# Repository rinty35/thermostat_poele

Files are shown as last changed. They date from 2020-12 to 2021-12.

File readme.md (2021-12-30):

# Thermostat DIY Poêle à pellets
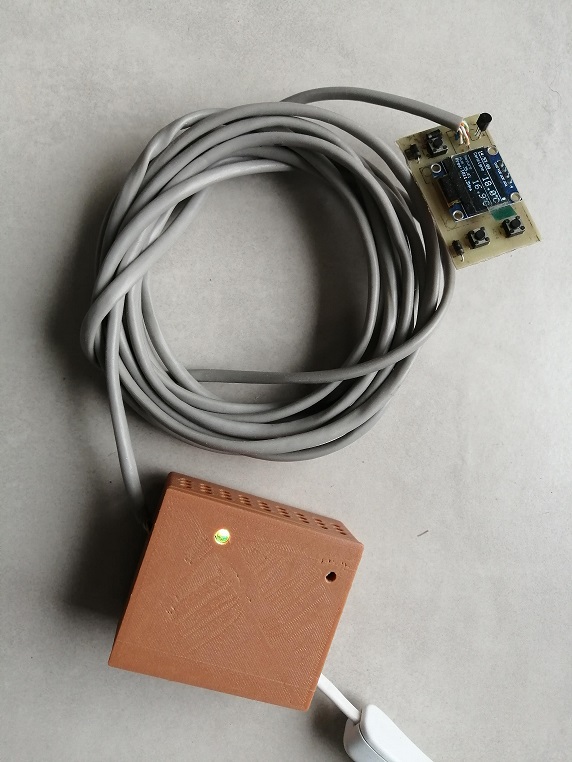
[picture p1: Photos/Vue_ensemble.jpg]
Photos du thermostat

## Le concept
Il s’agit d’un thermostat connecté pour tout chauffage nécessitant un contact sec pour forcer le déclanchement. Son usage premier était donc à destination d’un poêle à pellets Il pourrait servir à déclencher toutes sortes de chauffage. A cette fonction principale a été ajoutée une fonctionnalité de station météo connectée.
## Le matériel nécessaire
#### Electronique module principal
-	Alimentation a découpage HILink / fusible / varistance
-	Circuit Relais 5v / transistor / résistance / diode de roue libre
-	Puce principale ESP8266
-	Capteur météo BME680
-	Diode RVB / bouton poussoir
#### Electronique module de controle
-	Capteur de température DS18B20
-	Boutons poussoir de réglage de température / marche forcée
-	Affichage LCD
## Librairies utilisées
-	Onwire
-	DallaTemperature
-	ESP8266Webserver
-	WifiManager
-	ArduinoJson
-	ESP8266FtpServer
## Modélisation 3D
Conception sous Freecad
## Fonctionnement
1.	Sur le boitier principal : appui long pour réinitialiser le boitier (clignotement de la LED du boitier en rouge)
2.	A la première connexion : portail de connexion wifi et paramétrage accès web / client OVH Dyndns
3.	Au second démarrage affichage de l’IP sur le réseau local lors du démarrage (LED couleur blanche)
4.	Passage de la LED en couleur verte une fois le démarrage finalisée / bleu lors d’une mesure / rouge en cas de disfonctionnement / violet en cas déclanchement marche forcée / jaune en cas de chauffage sur consigne thermostat. 

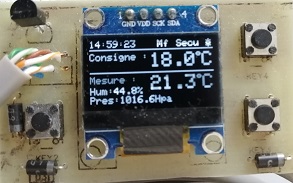
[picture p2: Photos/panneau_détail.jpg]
Photos panneau de controle


Le panneau de contrôle affiche l’heure, la température de consigne, la température actuelle, l’hygrométrie, la pression atmosphérique. A cela s’ajoute dans la partie supérieure droite une étoile quand le chauffage est allumé, le message « sécu » quand le démarrage a eu lieu dans les 15minutes pour éviter des cycles de démarrage/extinction trop rapprochés du poêle, le message « Mf » pour marche forcée

Les boutons de droites servent à régler la consigne celui de gauche a allumer le poêle même si la consigne ne le nécessite pas (marche forcée)

## Portail WEB
Le portail web offre les mêmes fonctionnalités que le panneau de contrôle en ajoutant des options de réglage et la consultation d’historiques. L’accès est contrôlé via le mot de passe indiqué lors de la configuration

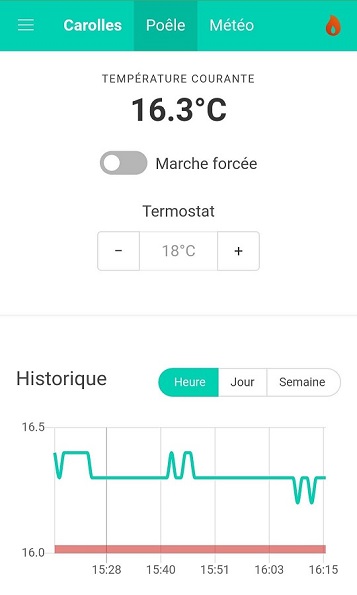
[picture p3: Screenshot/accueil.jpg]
Photos page accueil


L’accueil affiche si le poêle chauffe (flamme rouge) ou non, la température courante, la possibilité d’activer la marche forcée ainsi que le réglage de la température de consigne. Un historique de la température est disponible avec en rouge les périodes de chauffage

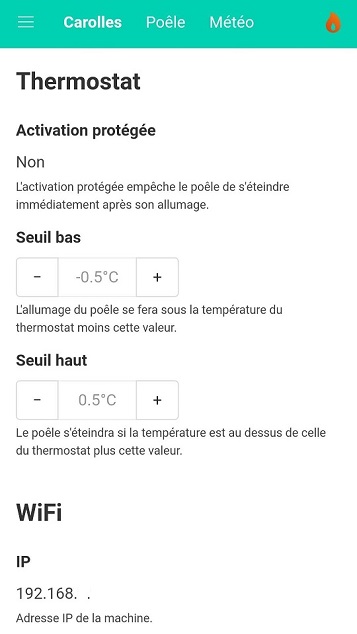
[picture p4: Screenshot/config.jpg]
Photos réglages


La page de réglage affiche si le mode protection (interdisant un allumage de moins de 15min) est activé et si oui pour combien de temps.

Elle permet le réglage des seuils de déclanchement par 0,5°C en dessous et au-dessus de la température de consigne (pour éviter des cycles d’allumage/extinction trop fréquent)
-	Allumage quand la T° est sous la consigne + seuil bas
-	Extinction quand la T° est au-dessus de la consigne + seuil haut

Elle affiche les informations concernant le wifi (IP, SSID du réseau, qualité du signal)

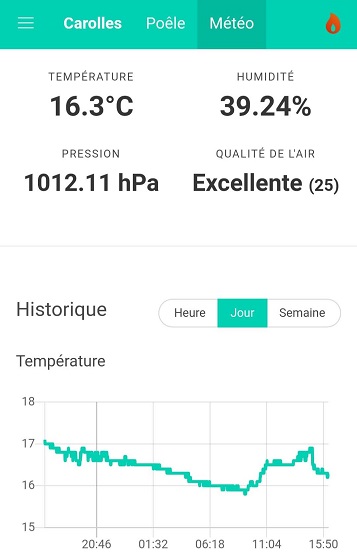
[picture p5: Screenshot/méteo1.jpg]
Photos meteo


L’onglet météo affiche les informations actuelles et historiques sur la température, hygrométrie, la pression atmosphérique et la qualité de l’air. L’historique est lissé pour gagner en volumétrie de stockage sur la puce et surtout en temps de traitement pour l’affichage.
## API
Il est possible de récupérer les informations via un fichier json dans une suite domotique type jeedom
http://ip/api/mesure.json
-	t > température
-	h > hygrométrie
-	pression > pression atmosphérique
## Service FTP
Il est possible d’accéder aux données en FTP avec le même couple utilisateur/password que pour le site web

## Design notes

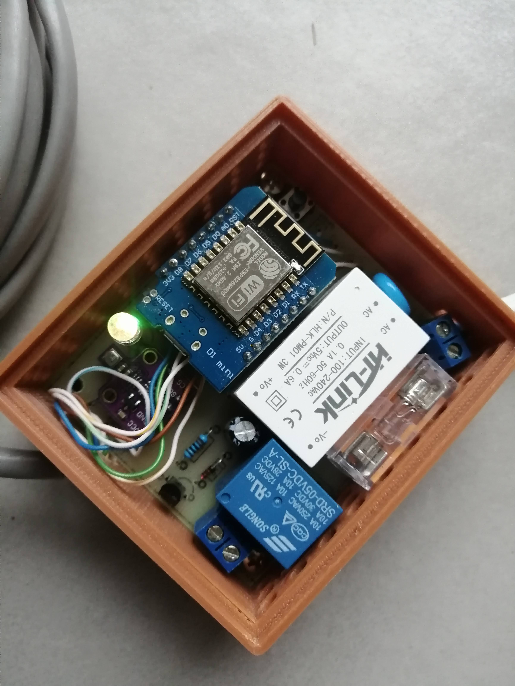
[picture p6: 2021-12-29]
Photos/Vue_interieure.jpg

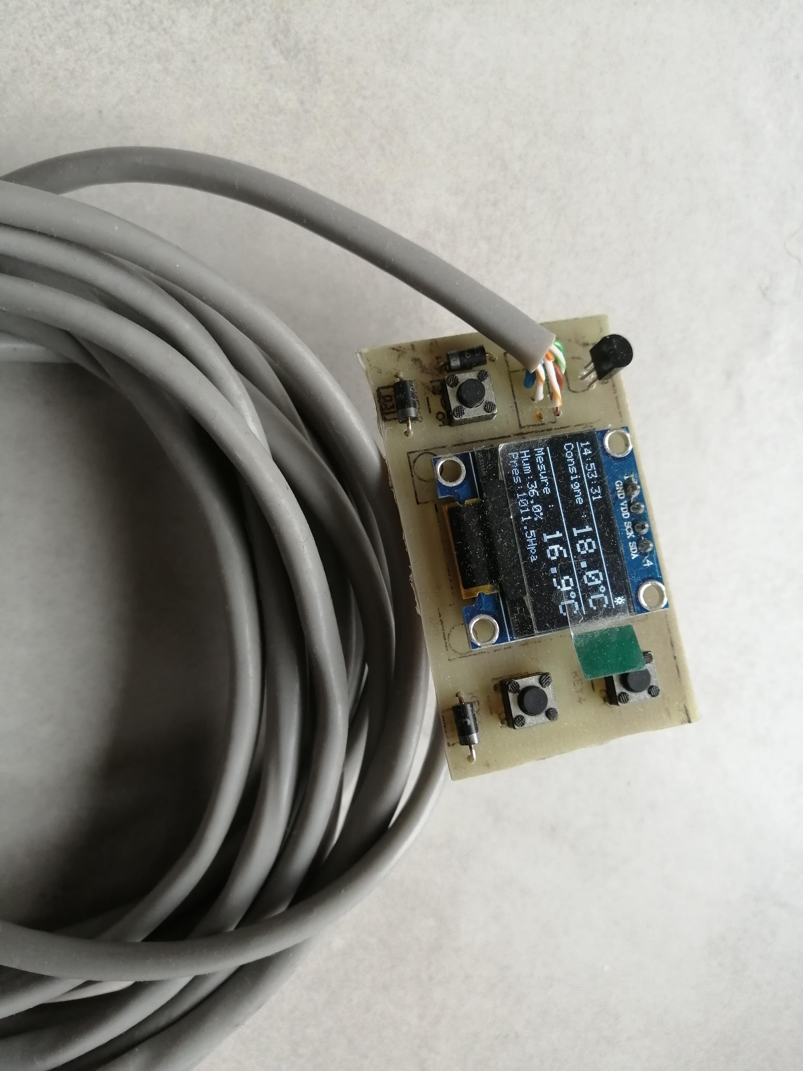
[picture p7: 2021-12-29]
Photos/Panneau_control.jpg

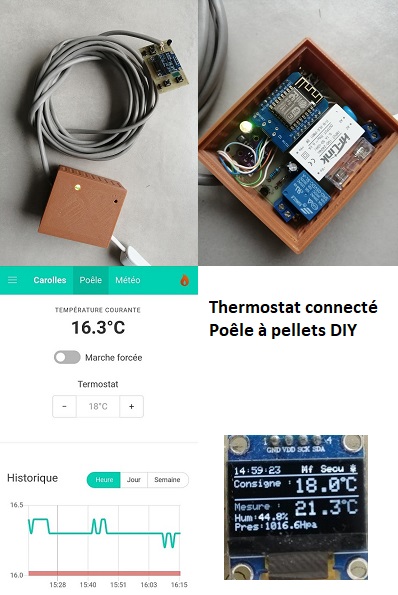
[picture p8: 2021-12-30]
Photos/synthese.jpg

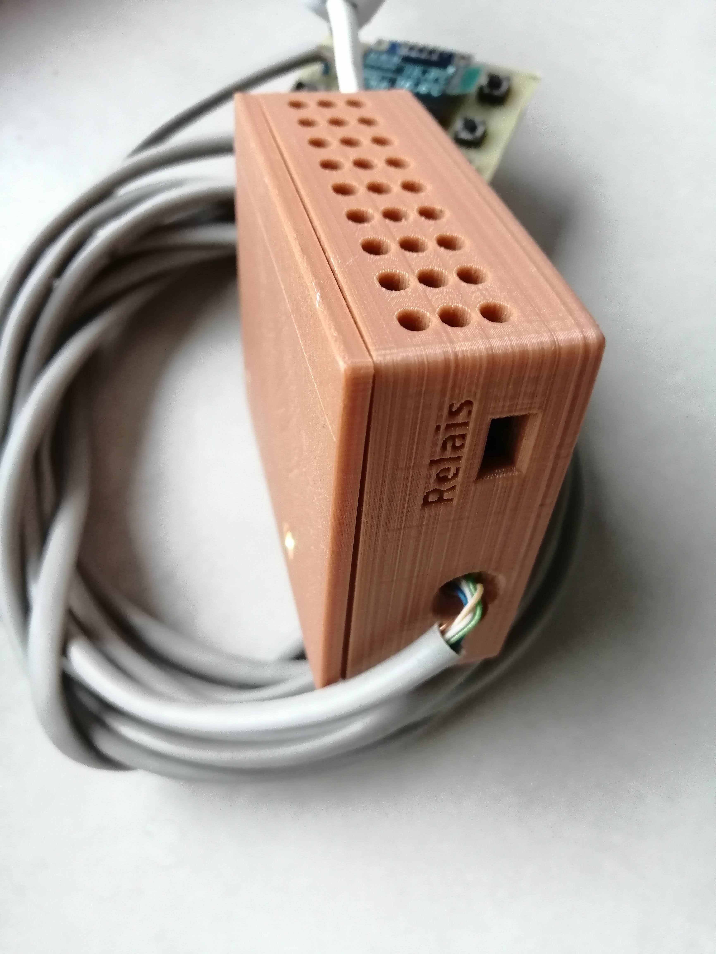
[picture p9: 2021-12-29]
Photos/vue_boitier.jpg

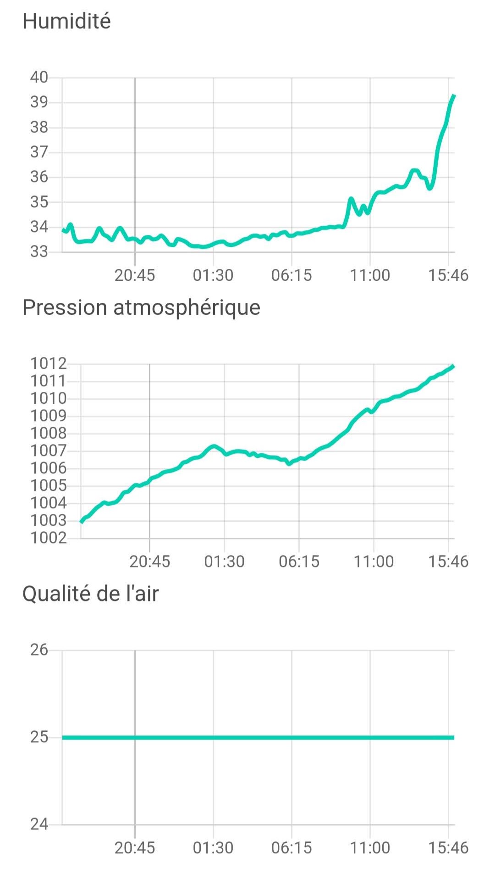
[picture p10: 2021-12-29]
Screenshot/météo2.jpg

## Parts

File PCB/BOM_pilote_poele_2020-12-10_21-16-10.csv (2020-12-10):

ID | Name | Designator | Footprint | Quantity | Manufacturer Part | Manufacturer | Supplier | Supplier Part
1 | HLK-PM01 | U1 | PWRM-TH_HLK-PM01 | 1 | HLK-PM01 | HI-LINK | LCSC | C209903
2 | RGB_LED_5mm | LED1 | RGB-5MM | 1 | φ5 RGB LED | KENTO | LCSC | C32985
3 | CONNECTOR 2 PIN | U8 | CONNECTOR 2 PIN | 1
4 | SRD-05VDC-SL-C | K1 | RELAY_SRD-05VDC-SL-C | 1
5 | 3_Pin_connector | U6 | PIN 3 | 1 | pin 3
6 | bornier 2P | U4,U2 | BORNIER 2P | 2 | bornier |  |  | https://fr.aliexpress.com/item/10pcs-2-Poles-2-Pin-2-54mm-0-1-PCB-Universal-Screw-Terminal-Block-Connector-Free/32556311867.html
7 | WEMOS | U3 | WEMOS | 1
8 | Conector_4_pines I2C | U7 | SIP-2.54MM-4P-CJT-H8.54 | 1
9 | 5x20 BLX-Atype Fuse holder XC-7 | F1 | FUSE-TH_L22.6-W9.0 | 1 | 5x20 BLX-Atype Fuse holder XC-7 | XCFuse | LCSC | C3131
10 | 431KD10 | R1 | RES-TH_L12.5-W6.7-P7.50-D1.2-S6.30 | 1 | 431KD10 | Brightking | LCSC | C123332
11 | K4-6×6_TH | KEY1 | KEY-TH_4P-L6.0-W6.0-P4.50-LS6.5 | 1 | K2-1102DP-E4SW-04 | 韩国韩荣 | LCSC | C136684
12 | 270 | R4 | R_AXIAL-0.4 | 1
13 | 200 | R2 | R_AXIAL-0.4 | 1
14 | 100 | R8 | R_AXIAL-0.4 | 1
15 | 150 | R3 | R_AXIAL-0.4 | 1
16 | 10K | R5 | R_AXIAL-0.4 | 1
17 | 1K | R6 | R_AXIAL-0.4 | 1
18 | PN2222 | Q1 | ONSC-TO-92-3-29-11_AM_BL | 1
19 | 220u | C3 | CAP-D6.3×F2.5 | 1
20 | 4,7K | R7 | R_AXIAL-0.4 | 1
21 | TB 128X64 OLED | DISP1 | TB 128X64 OLED | 1
22 | 1N4148 | D1 | DO-35_BD2.0-L4.0-P8.00-D0.5-FD | 1 | 1N4148 | SEMTECH | LCSC | C14516
23 | BME280 | U5 | BME280 6PINS SIPPY | 1
24 | 0.1u | C2 | RAD-0.1 | 1

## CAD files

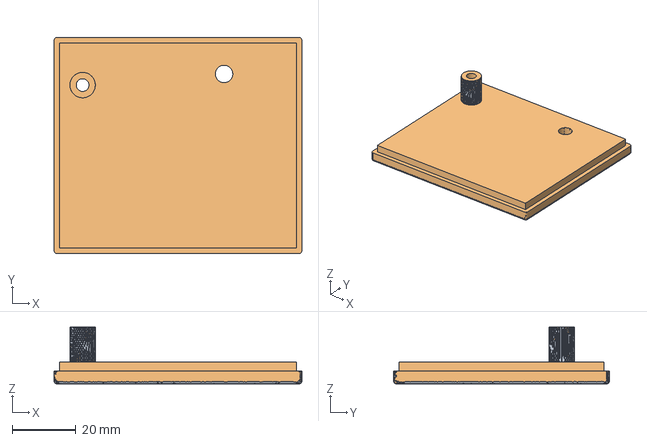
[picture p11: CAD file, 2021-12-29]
Boitier_3D/Boitier_couvercle.FCStd
78.0 x 68.0 x 17.9 mm
Cut (Meshed)001

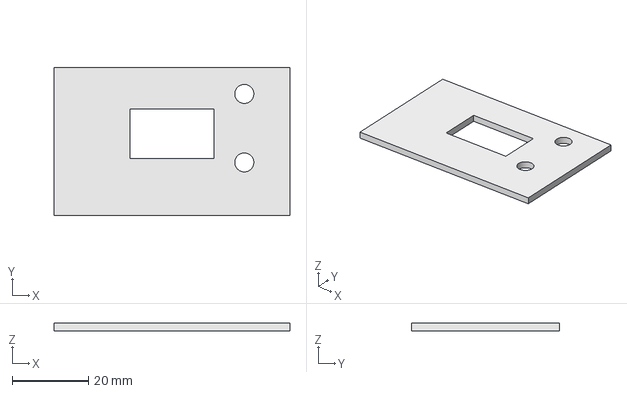
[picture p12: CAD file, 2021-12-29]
Boitier_3D/Boitier_extension.FCStd
62.0 x 39.0 x 2.00 mm

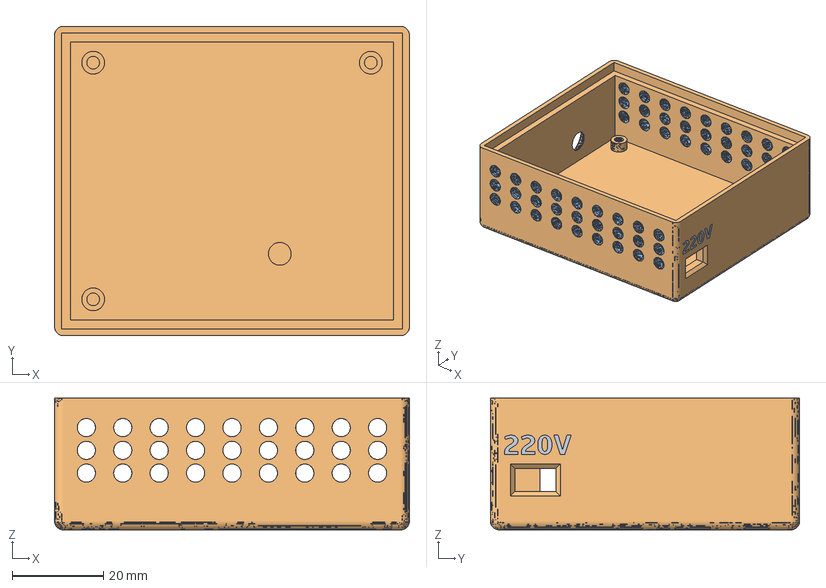
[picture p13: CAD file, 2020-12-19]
Boitier_3D/Boitier_bas.FCStd
78.0 x 68.0 x 29.0 mm
Cut001 (Meshed)

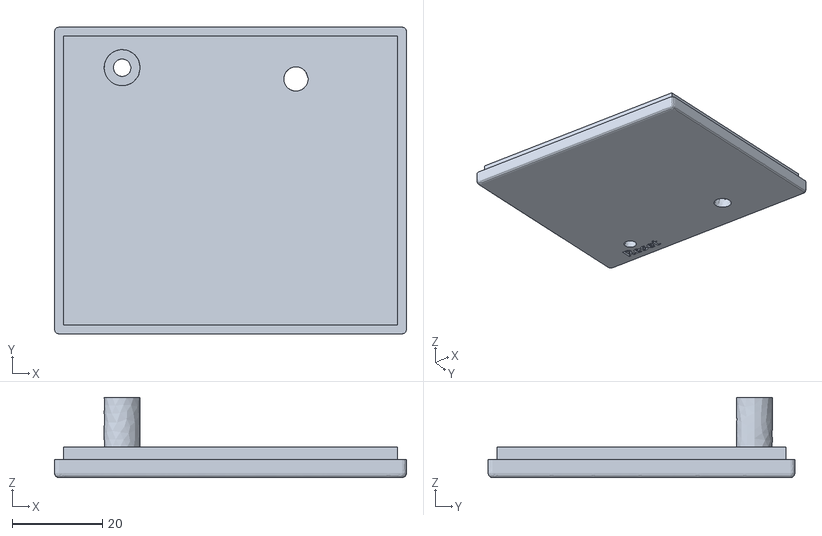
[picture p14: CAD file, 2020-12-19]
Boitier_3D/couvercle_V0.stl
78.0 x 68.0 x 17.8

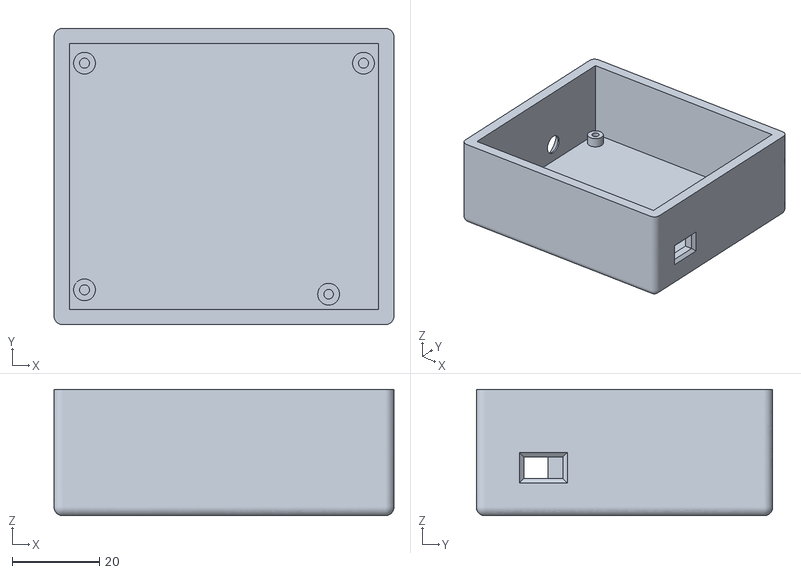
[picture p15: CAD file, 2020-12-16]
Boitier_3D/boitier_bas_V0.stl
78.0 x 68.0 x 29.0

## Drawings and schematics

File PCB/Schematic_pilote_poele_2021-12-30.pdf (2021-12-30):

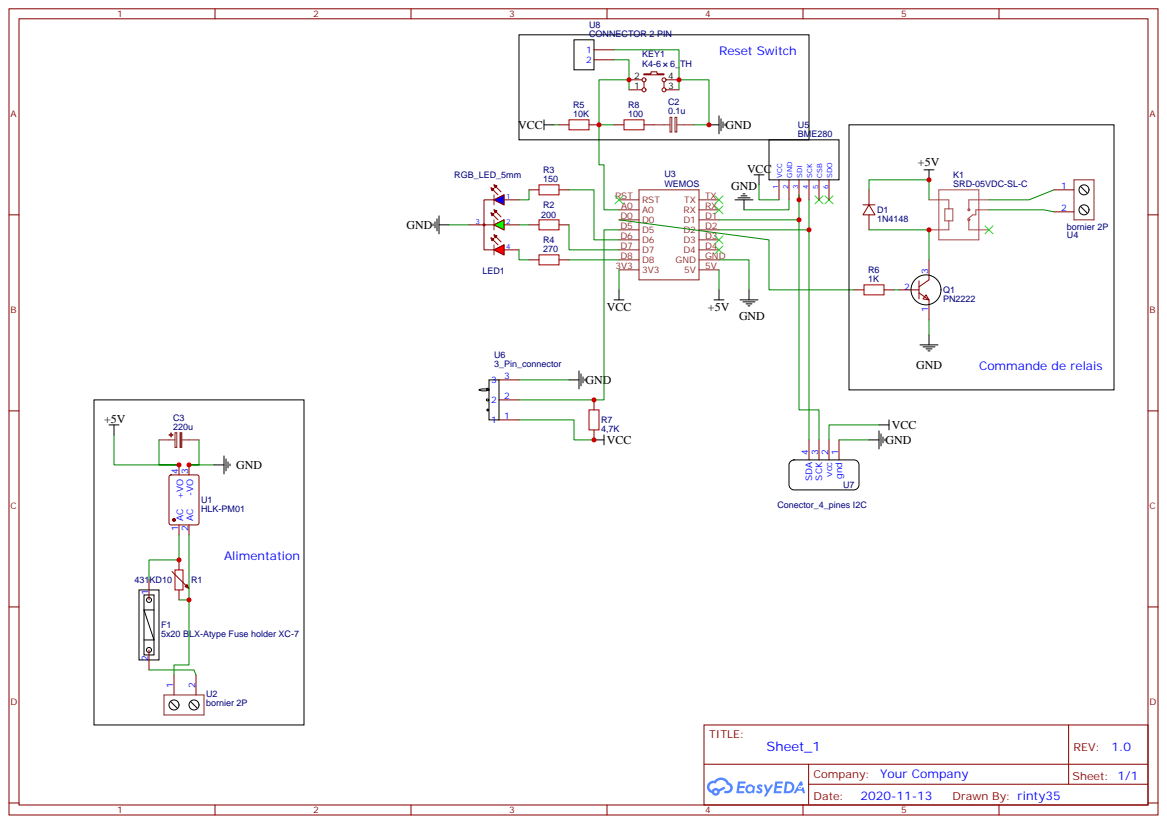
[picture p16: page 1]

5x20 BLX-Atype Fuse holder XC-7

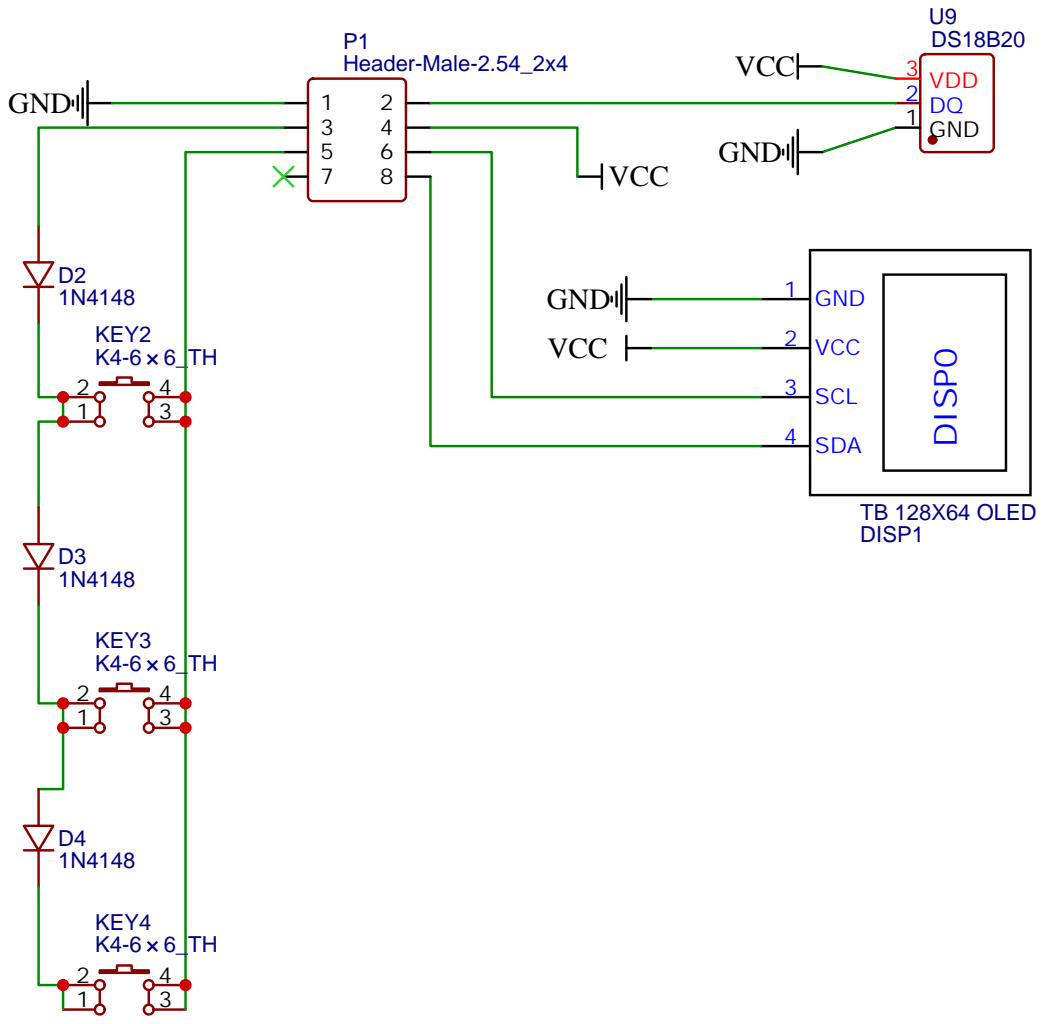
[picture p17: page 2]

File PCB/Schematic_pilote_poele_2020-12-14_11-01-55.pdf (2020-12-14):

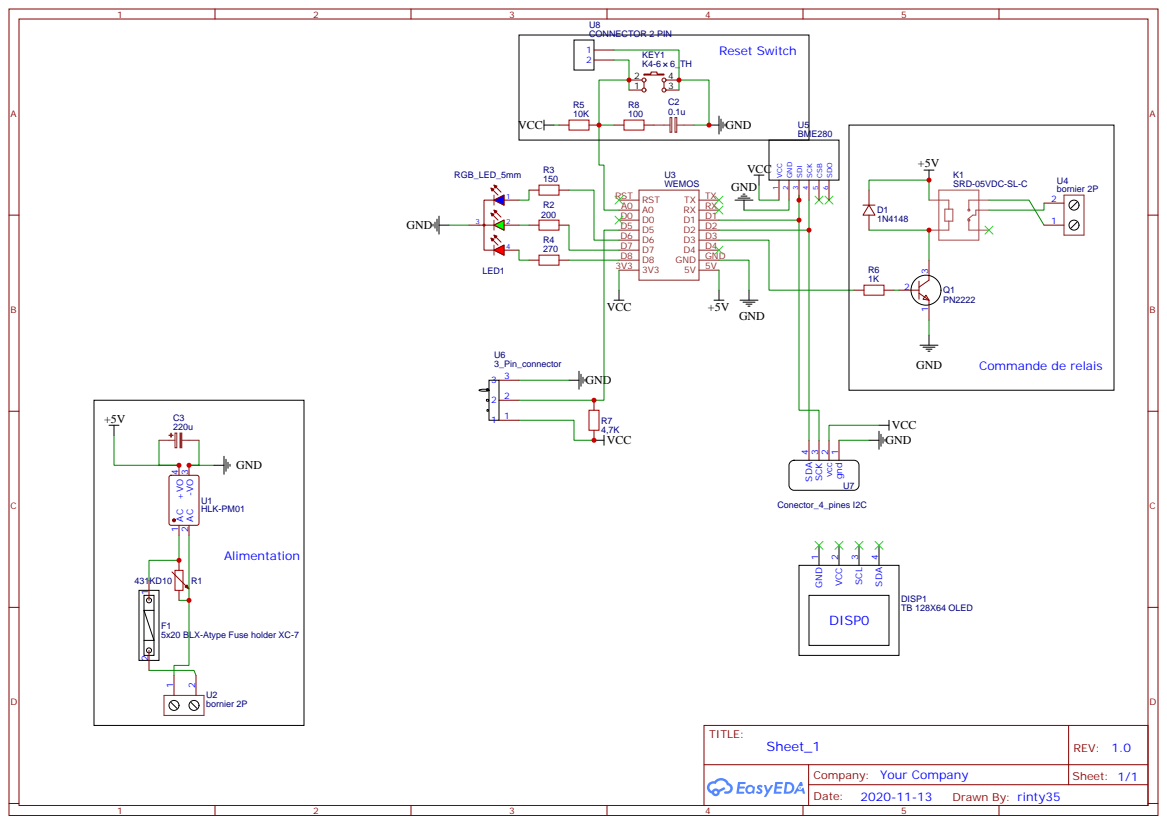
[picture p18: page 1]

5x20 BLX-Atype Fuse holder XC-7

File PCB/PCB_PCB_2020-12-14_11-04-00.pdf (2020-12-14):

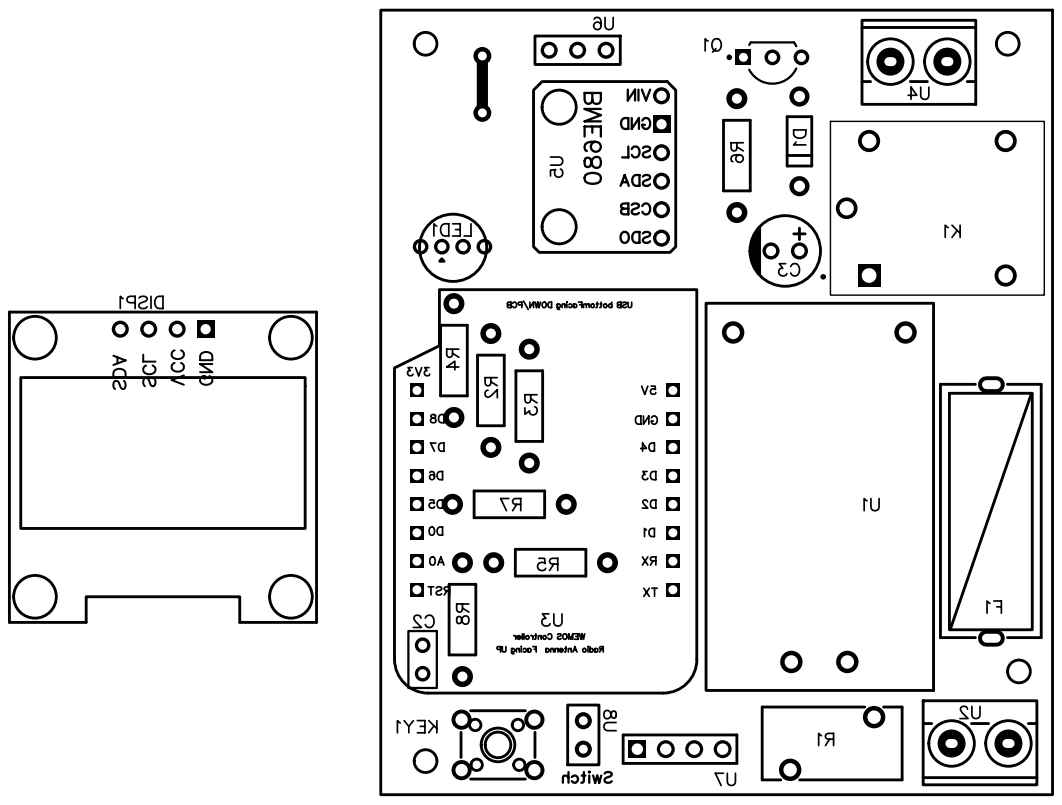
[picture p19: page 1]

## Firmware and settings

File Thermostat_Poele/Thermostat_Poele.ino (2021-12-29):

#include <ArduinoOTA.h>
#include <OneWire.h> //Librairie du bus OneWire
#include <math.h>
#include <DallasTemperature.h> //Librairie du capteur
#include "FS.h"
#include <ESP8266WebServer.h>
#include <WiFiManager.h>
#include <NTPClient.h>
#include "ESP8266WiFi.h"
#include <ArduinoJson.h>
#include <ESP8266FtpServer.h>
FtpServer ftpSrv;
#include "meteo.h"
//librairie OLED
#include <Wire.h>
#include <Adafruit_GFX.h>
#include <Adafruit_SSD1306.h>
#define SCREEN_WIDTH 128 // OLED display width, in pixels
#define SCREEN_HEIGHT 64 // OLED display height, in pixels
// Declaration for an SSD1306 display connected to I2C (SDA, SCL pins)
Adafruit_SSD1306 display(SCREEN_WIDTH, SCREEN_HEIGHT, &Wire, -1);


#include <ESP8266HTTPClient.h>
#include "bsec.h" // Librairie Bosh BME680
#include "boutton.h"
#define BOUNCE_DELAY  5 // pause anti-rebonds = 5 ms
#define Vert D7
#define Rouge D8
#define Bleu  D6
#define ds18b20 D5
#define PIN_RESET_BUTTON A0
#define RELAIS D0



Boutton ResetBoutton(10, BOUNCE_DELAY);
Boutton PlusBoutton(155, BOUNCE_DELAY);
Boutton MoinsBoutton(105, BOUNCE_DELAY);
Boutton MFBoutton(55, BOUNCE_DELAY);


// Create an object of the class Bsec https://github.com/BoschSensortec/BSEC-Arduino-library
Bsec iaqSensor;

// Set global to avoid object removing after setup() routine
//Pinger pinger;

ESP8266WebServer server(80); //server web
OneWire oneWire(ds18b20); //Bus One Wire sur la pin 2 de l'arduino
DallasTemperature sensors(&oneWire); //Utilistion du bus Onewire pour les capteurs
DeviceAddress sensorDeviceAddress; //Vérifie la compatibilité des capteurs avec la librairie
WiFiManager wifiManager;

/* Couleurs (format RGB) */
byte COLOR_BLACK[3] = {0, 0, 0};
byte COLOR_RED[3] = {255, 0, 0};
byte COLOR_GREEN[3] = {0, 100, 0};
byte COLOR_BLUE[3] = {0, 0, 255};
byte COLOR_MAGENTA[3] = {255, 0, 255};
byte COLOR_CYAN[3] = {0, 100, 255};
byte COLOR_YELLOW[3] = {255, 100, 0};
byte COLOR_WHITE[3] = {255, 100, 255};
byte *couleur_fonction = &COLOR_GREEN[0];
byte *couleur_mesure = &COLOR_BLUE[0];
byte *couleur_error = &COLOR_RED[0];
byte *couleur_forcee = &COLOR_MAGENTA[0];
byte *couleur_haut = &COLOR_YELLOW[0];
byte *couleur_statut;
//const byte luminosite = 5; //pourcentage
#define luminosite 5


//const unsigned long appuilong = 3000; //délais d'appui sur le boutton reset en ms
#define appuilong 3000
unsigned long millisStart; // calcul du délais du boutton reset

WiFiUDP ntpUDP; // Define NTP Client to get time
NTPClient timeClient(ntpUDP, "pool.ntp.org" ); //, utcOffsetInSeconds); heure

unsigned long DateMesure;
unsigned long PrevDateMesure;
short int temp=-127; // mesure de la température

short int tab_temp[2];
bool tab_statut[2];
short int tab_mesure[10];
byte nbenr = 0;
bool StatutWifi = true ;
//IPAddress gateway;
bool shouldSaveConfig = false;
String URL_MAJ;
char domaine[100] ="votre domaine";
char user_web[12] = "Utilisateur";
char mdp_web[13] = "Mot de passe";
 
//const unsigned long DelaisTestWifi = 5*60*1000; // Délais de contrôle du wifi
#define DelaisTestWifi 300000
//const short int DelaisSecu = 15*60; // Délais de sécurité entre un allumage et l'extinction en seconde
#define DelaisSecu 900
//const unsigned long DelaisMesure = 10 * 1000; // ecart entre deux mesures
#define DelaisMesure 10000
unsigned long MillisMesure =  millis(); // calcul des délais mesures
unsigned long MillisLCD =  millis(); // actualisation LCD

#define FILE_STATUT "/statut.json"
const size_t capacity_statut = JSON_OBJECT_SIZE(9) + 100;
bool Mf, S = 0;
unsigned short int Tc = 200;
signed short int Tob = -5;
byte Toh = 5; // décalage de déclanchement en °
unsigned long Secu = 0;

#define HISTORY_FILE_TOTAL "/historytotal.json"
//const byte TailleEnregistrement = 19;//taille de la chaine + 1 (retour chariot)
#define TailleEnregistrement 19
//const short int NbEnregistrement =  10080; // 7j x 24h x 60min ;
#define NbEnregistrement 10080
//const unsigned long DelaisEnr = 1000 * 60; // ecart entre deux sauvegardes
#define DelaisEnr 60000
unsigned long MillisEnr =  MillisMesure; // calcul des délais d'enregistrement

#define HISTORY_METEO_HEURE "/historymeteoheure.json"
#define HISTORY_METEO_QUOTIDIEN "/historymeteoquotidien.json"
#define HISTORY_METEO_HEBDO "/historymeteohebdo.json"
//const short int     SizeHistMeteoHeure = (60 * 60 * 1000) / DelaisEnr;
Meteo Meteoheure(60, HISTORY_METEO_HEURE); //60 enregistrement
Meteo Meteoquotidien(96, HISTORY_METEO_QUOTIDIEN); //96 un enregistrement toutes les 15mins
Meteo Meteohebdo(168, HISTORY_METEO_HEBDO); //un enregistrement par heure
//const unsigned long DelaisEnrQuo = 1000 * 60 * 15; // ecart entre deux sauvegardes
#define DelaisEnrQuo 900000
unsigned long MillisEnrQuo =  MillisMesure; // calcul des délais d'enregistrement
//const unsigned long DelaisEnrHebdo = 1000 * 60 * 60; // Toutes les heures
#define DelaisEnrHebdo 3600000
unsigned long MillisEnrHebdo =  MillisMesure; // calcul des délais d'enregistrement
unsigned int humidite,  humiditehebdo = 0;
unsigned int pression, pressionhebdo = 0 ;
unsigned int IAQ, IAQhebdo = 0;
byte nbenrmeteo, nbenrmeteohebdo = 0;


bool RESET = true; // statut du boutton RESET
bool StateBoutton = false; // statut wifi 


void saveConfigCallback () {
  Serial.println("Should save config");
  shouldSaveConfig = true;
}

void sendMesures() {
    String message = "[{\"d\":" + (String)DateMesure + ",\"t\":";
    message += inttofloat(temp) ;
    message += ",\"iaq\":" + (String)(iaqSensor.iaq);
    message += ",\"pression\":" + (String)(iaqSensor.pressure/100);
    message += ",\"h\":" + (String)(iaqSensor.humidity);
    message += "}]";
    server.send(200, "application/json", message);
    //Serial.println("Mesures envoyees");
    //Serial.println(message);
}

void loadStatut(){
  StaticJsonDocument<capacity_statut> Tab_Statut; //calcul via https://arduinojson.org/v6/assistant/
  File file = SPIFFS.open(FILE_STATUT, "r");
  if (!file){
    Serial.println("Aucun statut existe");
    updatestatut ();
  } else {
    if (  file.size()== 0 ) {
      Serial.println("Fichier statut vide !");
      updatestatut ();
    } else {
      DeserializationError error = deserializeJson(Tab_Statut, file);
      if (error) {
        Serial.println("Impossible de lire le JSON");
        Serial.println(error.c_str());
      } else {
        Mf= Tab_Statut["mf"];
        Tc=floattoint(Tab_Statut["tc"]);
        Tob=floattoint(Tab_Statut["b"]);
        Toh=floattoint(Tab_Statut["h"]);
        Secu= 0;
        S = 0; // au chargement on suppose que le poele est arreté (coupure de courant)
        Tab_Statut["s"] = 0;
        serializeJson(Tab_Statut,file);
        Serial.println("Paramètre : \n  Marche Forcée : " + (String)Mf + "\n  Température Consigne : " + (String)inttofloat(Tc) +"\n  Température Offset bas : " + (String)inttofloat(Tob) +"\n  Température Offset Haut : " + (String)inttofloat(Toh) + "\n  Statut : " + (String)S + "\n  Sécurité : " + (String)Secu );
      }
    }
  }
  file.close();
}
void updatestatut () {
  StaticJsonDocument<capacity_statut> Tab_Statut; //calcul via https://arduinojson.org/v6/assistant/
  File file = SPIFFS.open(FILE_STATUT, "w");
  Tab_Statut["mf"] = Mf;
  if (Tc <100) {
    Tc = 100;
  } else if (Tc>300){
    Tc=300;
  }
  Tab_Statut["tc"] = inttofloat(Tc);
  Tab_Statut["b"] = inttofloat(Tob);
  Tab_Statut["h"] = inttofloat(Toh);
  Tab_Statut["s"] = S;
  Tab_Statut["se"] = Secu;
 // Tab_Statut["ip"] = IpAdress2String (WiFi.localIP());
  Tab_Statut["ip"] = WiFi.localIP().toString();
  Tab_Statut["rssi"] = WiFi.RSSI();
  Tab_Statut["ssid"] = WiFi.SSID();
  serializeJson(Tab_Statut,file);  
  file.close();
}


void majstatut(){
  char json[1000];
  File file = SPIFFS.open(FILE_STATUT, "w");
  StaticJsonDocument<capacity_statut> Tab_Statut_temp; //calcul via https://arduinojson.org/v6/assistant/
  float tmp;
  if (server.hasArg("plain")== false){ //Check if body received
    server.send(200, "text/plain", "Body not received");
    return;
  }
  DeserializationError error = deserializeJson(Tab_Statut_temp, server.arg("plain"));
  if (error) {

    Serial.println("Impossible de lire le JSON - Impossible to read JSON file");
    Serial.println(error.c_str());
    server.send(200, "text/plain", "Json incorecte");
  } else {

    tmp = Tab_Statut_temp["tc"];
    if (tmp != 0){
     Tc = floattoint(Tab_Statut_temp["tc"]);
    }
    Mf= Tab_Statut_temp["mf"] | Mf;
    if (Tab_Statut_temp["b"]<=-0.5){
      Tob = floattoint(Tab_Statut_temp["b"]);
    }  
    if (Tab_Statut_temp["h"]>=0.5){
      Toh = floattoint(Tab_Statut_temp["h"]);
    } 
    S=Tab_Statut_temp["s"] | S;
    Serial.println("Paramètre : \n  Marche Forcée : " + (String)Mf + "\n  Température Consigne : " + (String)inttofloat(Tc) +"\n  Température Offset bas : " + (String)inttofloat(Tob) +"\n  Température Offset Haut : " + (String)inttofloat(Toh) + "\n  Statut : " + (String)S + "\n  Sécurité : " + (String)Secu );
    
    Tab_Statut_temp["mf"] = Mf;
    Tab_Statut_temp["tc"] = inttofloat(Tc);
    Tab_Statut_temp["b"] = inttofloat(Tob);
    Tab_Statut_temp["h"] = inttofloat(Toh);
    Tab_Statut_temp["s"] = S;
    Tab_Statut_temp["se"] = Secu;
//    Tab_Statut_temp["ip"] = IpAdress2String (WiFi.localIP());
    Tab_Statut_temp["ip"] = WiFi.localIP().toString();
    Tab_Statut_temp["rssi"] = WiFi.RSSI();
    Tab_Statut_temp["ssid"] = WiFi.SSID();
    serializeJson(Tab_Statut_temp,json);
    server.send(200, "application/json", json);
    updatestatut ();
  }
  file.close();
}

void insmesure(){
// Format du fichier Timestamp date mesure, temperature , statut poele
  File file ;
  String buffer;
  int dateenr;
  char char_array[TailleEnregistrement];

  if (tab_statut[0] == tab_statut[1] && tab_statut[1] == S && tab_temp[0] == tab_temp[1] && tab_temp[1] == temp ){ // test pour MAJ ou insertion
    file = SPIFFS.open(HISTORY_FILE_TOTAL, "r+");
    //maj fichier
    file.seek((TailleEnregistrement), SeekEnd); //positionnement sur l'enregistrement avant dernier.
    Serial.print("valeur mise à jour : ");
  } else {
    tab_statut[0] = tab_statut[1]; // remplacement de l'enregistrement N+2 par N+1
    tab_temp[0] = tab_temp[1];  
    file = SPIFFS.open(HISTORY_FILE_TOTAL, "a+");
    buffer = file.readStringUntil('\n');// récupération de la premère ligne
    if (!buffer.equals("")){
      buffer.toCharArray(char_array,TailleEnregistrement);
      dateenr = atoi(strtok(char_array, ","));
      Serial.println ("premier enregistrement : " + (String)dateenr);
    }

    // insérer fichier
    if ((file.size() >= ((TailleEnregistrement) * NbEnregistrement) || dateenr < (DateMesure - (NbEnregistrement +(24*60) ) * 60))||(dateenr>DateMesure) ){ // test taille maximale ou premier enregistrement datant de plus de 8j
      Serial.println("taille du fichier max ou 7J d'enregistrement présent - rotation du fichier");
      File filetemp = SPIFFS.open("/filetemp.txt", "w");
      //file.seek((TailleEnregistrement), SeekSet);
      Serial.println("reecriture du fichier");
      Serial.print("*");
      //filetemp.println(buffer);
      while (file.available()) {
        Serial.print("-");
        buffer = file.readStringUntil('\n');// récupération de la premère ligne
        buffer.toCharArray(char_array,TailleEnregistrement);
        //Serial.println(buffer);
        if (!buffer.equals("")){
          dateenr = atoi(strtok(char_array, ","));
          if ((dateenr >= (DateMesure - NbEnregistrement * 60))&&(dateenr<DateMesure)){ //récupération des enregistrements quand la date dans les 7J et pas au dessus du dernier enregistrement
            filetemp.print(buffer +"\n");
          }
        }

        //filetemp.print(file.readStringUntil('\n')+"\n");
      }
      Serial.print("*");
      file.close();
      Serial.println("Fin de reecriture du fichier et suppression du fichier total");
      SPIFFS.remove(HISTORY_FILE_TOTAL);
      filetemp.close();
      Serial.println("Renommage du fichier");
      SPIFFS.rename("/filetemp.txt",HISTORY_FILE_TOTAL );
      file = SPIFFS.open(HISTORY_FILE_TOTAL, "a+");
    }
    Serial.print("valeur insérée : ");
  }
  // Mise à jour de la date mesure
  tab_statut[1] = S;
  tab_temp[1] = temp;
  
  String message =  (String)DateMesure + ",";
  if (temp >= 100) { // sécurisation de l'écriture du fichier pour avoir toujours la meme taille
    message += inttofloat(temp) ;
  } else if (temp >= 0){ //température entre 0 et 9.99
    message += "0";
    message += inttofloat(temp) ;
  } else {
    message += inttofloat(temp) ;
  }
  message += "," + (String)S;
  message += "\n";

 // message += "}\n";
  if (message.length()!=TailleEnregistrement){ // controle que la taille de l'enregistrment est corercte
    Serial.println("Taille d'enregistrement incorecte : " + (String)message.length() + " - " + (String)TailleEnregistrement);
  }else{
    Serial.println( message);
    file.print(message);
  //Serial.println (file.size ());
  }
  file.close();
}
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
void loop() {
  static unsigned long MillisTestWifi = millis();
 // display.startscrollright(0x00, 0x0F);
  server.handleClient();
  ftpSrv.handleFTP(); 
  ArduinoOTA.handle();
  
//Serial.println("Wlconnect : " + (String)WL_CONNECTED + " : " + (String)WiFi.status());

  //Gestion du boutton Reset
  bouttonReset ();
  //Serial.print ("lecture bouton : ");
  //Serial.println (analogRead(A0));

  //controle du wifi
  if (millis()-MillisTestWifi>=DelaisTestWifi){
    MillisTestWifi = millis();
    updatestatut ();
    Serial.print("test de la connexion wifi : ");
    if (WiFi.status()!= WL_CONNECTED){
        Serial.println("wifi KO");
        DisplayLCD("Wifi KO");
        couleur_statut=&couleur_error[0];
        displayColor(&couleur_statut[0], luminosite);
        WiFi.reconnect();
        StatutWifi = false;
      } else if (StatutWifi == false) {
        Serial.println("Wifi de nouveau OK");
        DisplayLCD("Wifi OK");
        StatutWifi = true;
        if (Mf==true){ //marche forcée 
          couleur_statut=&couleur_forcee[0];
        } else if ( S ==true){ 
          // en marche sans forçage
          couleur_statut=&couleur_haut[0];
        } else { // éteint
          couleur_statut=&couleur_fonction[0];
        }
        displayColor(&couleur_statut[0], luminosite);
      }else{
        Serial.println("Wifi OK");
        DisplayLCD("Wifi OK");
        dyndns ();
    }
  }    

  //mesure
  if (millis()-MillisMesure > DelaisMesure){
    MillisMesure = millis();
    displayColor(&couleur_mesure[0], luminosite);  // turn the LED on (HIGH is the voltage level)
    timeClient.update();
    delay(100);
    sensors.requestTemperatures(); //Demande la température aux capteurs
    temp = floattoint (sensors.getTempCByIndex(0));
    DateMesure = timeClient.getEpochTime();
    if (temp != -127 && DateMesure > PrevDateMesure){
      PrevDateMesure = DateMesure;
      ctrlchauff(); // controle d'enclenchement chauffage
      tab_mesure[nbenr]=temp;
      nbenr++;
      if (MillisMesure - MillisEnr > DelaisEnr ){
        MillisEnr = MillisMesure;
        if (iaqSensor.run()) { // If new data is available
          IAQ += floattoint(iaqSensor.iaq);
          pression += floattoint(iaqSensor.pressure/100);
          humidite += floattoint(iaqSensor.humidity);
          nbenrmeteo++;
          Meteoheure.Update(DateMesure,iaqSensor.pressure/100,iaqSensor.humidity,iaqSensor.iaq);
          if (MillisMesure - MillisEnrQuo > DelaisEnrQuo ){
            MillisEnrQuo = MillisMesure;
            Meteoquotidien.Update(DateMesure,round(inttofloat(pression)/nbenrmeteo*100)/100,round(inttofloat(humidite)/nbenrmeteo*100)/100,round(inttofloat(IAQ)/nbenrmeteo*100)/100);
            IAQhebdo += floattoint(iaqSensor.iaq);
            pressionhebdo += floattoint(iaqSensor.pressure/100);
            humiditehebdo += floattoint(iaqSensor.humidity);
            nbenrmeteohebdo++;
            //Serial.println("nbenr hebdo : " + (String)nbenrmeteohebdo + " Pression Hebdo : " + (String)pressionhebdo + " humidite hebdo : " + (String)humiditehebdo + " IAQ Hebdo : " + (String)IAQhebdo);
            nbenrmeteo=0;
            pression = 0;
            humidite=0;
            IAQ=0;
            if (MillisMesure - MillisEnrHebdo > DelaisEnrHebdo ){
              MillisEnrHebdo = MillisMesure;
              Meteohebdo.Update(DateMesure,round(inttofloat(pressionhebdo)/nbenrmeteohebdo*100)/100,round(inttofloat(humiditehebdo)/nbenrmeteohebdo*100)/100,round(inttofloat(IAQhebdo)/nbenrmeteohebdo*100)/100);
              nbenrmeteohebdo=0;
              pressionhebdo = 0;
              humiditehebdo=0;
              IAQhebdo=0;
            }
          }
        } else {
          checkIaqSensorStatus();
        }
        int mesure_total = 0 ;  // calcul de la moyenne des précédentes mesures
        for (int i = 1 ; i<nbenr-1 ; i++){
           mesure_total +=  tab_mesure[i];
        }
        temp = roundf(mesure_total/(nbenr-2));
        insmesure();
        nbenr = 0;
      } 
    }
    //DisplayLCD("");
    displayColor(&couleur_statut[0], luminosite);    // turn the LED off by making the voltage LOW
  }
  if (millis()-MillisLCD>=1000){
    MillisLCD = millis();
    DisplayLCD("");
  }
  delay(10);                       // wait for a 0,1 second
}


void displayColor(byte *couleur,byte lum) {
  //controle du pourcentage d'allumage des led 
  if (lum>100){lum=100;}
  analogWrite(Rouge, couleur[0]*lum/100);
  analogWrite(Vert, couleur[1]*lum/100);
  analogWrite(Bleu, couleur[2]*lum/100);
}

void DisplayLCD (String message){
    if (message == ""){
      timeClient.setTimeOffset(3600);
      message=timeClient.getFormattedTime();
      timeClient.setTimeOffset(0);
    }
    display.clearDisplay();
    display.setTextSize(1);
    display.setCursor(0, 0);
    display.print(message);
    display.setCursor(121, 0);
    if (S==true & Secu == 0) {
      display.setCursor(121, 0);
      display.cp437(true);
      display.write(15);      
    } else if (S==true & Secu != 0) {
      display.setCursor(90, 0);
      display.println("Secu");
      display.setCursor(121, 0);
      display.cp437(true);
      display.write(15);
    }
    if (Mf==true) {
      display.setCursor(70, 0);
      display.println("Mf");
     
    }
    display.drawLine(0, 9, 128, 9, WHITE);
    display.drawLine(0, 32, 128, 32, WHITE);
    display.setCursor(0, 13);
    display.println("Consigne :");
    display.setCursor(0, 36);
    display.println("Mesure :");
    display.setTextSize(2);
    display.setCursor(62, 13);
    display.print(inttofloat(Tc),1);
    display.setTextSize(1);
    display.cp437(true);
    display.write(248);
    display.setTextSize(2);
    display.print("C");
    display.setCursor(62, 36);
    display.print(inttofloat(temp),1);
    display.setTextSize(1);
    display.cp437(true);
    display.write(248);
    display.setTextSize(2);
    display.print("C");
    display.setTextSize(1);
    display.setCursor(0, 47);
    display.print("Hum:");
    display.print(iaqSensor.humidity,1);
    display.print("%");
    display.setCursor(0, 56);
    display.print("Pres:");
    display.print(iaqSensor.pressure/100,1);
    display.print("Hpa");
    display.display(); 
}
void DisplayChargement(String message){
  display.clearDisplay();
  display.setCursor(0, 0);
  display.print("Chargement...");
  display.setCursor(0, 10);
  display.print(message);
  display.display();
  delay(2000); 
}
void bouttonReset (){
  unsigned long millisCheck = millis();
  if (ResetBoutton.pressed()||ResetBoutton.pressedlong()) {
    RESET = false;
  } else if (PlusBoutton.pressed()){
    Tc = Tc +5;
    Serial.println("Nouvelle température de consigne " + (String)floattoint(Tc));
    updatestatut ();
    ctrlchauff();
    DisplayLCD("");
  } else if (MoinsBoutton.pressed()){
    Tc = Tc -5;
    Serial.println("Nouvelle température de consigne " + (String)floattoint(Tc));
    updatestatut ();
    ctrlchauff();
    DisplayLCD("");
  } else if (MFBoutton.pressed()){
    Mf = !Mf;
    if (Mf){
      Serial.println("Marche Forcée activée");
    } else {
      Serial.println("Marche Forcée arrêtée");
    }
    ctrlchauff();
    DisplayLCD("");
  } else {
    RESET = true;
  }

  if( StateBoutton == 0 && RESET == false ) { 
    millisStart=millisCheck;
    StateBoutton = 1;
    Serial.println("début appui Reset");
    displayColor(&couleur_error[0], 0);
    }
  if( StateBoutton == 1 && RESET == true ) { 
    StateBoutton = 0;
    displayColor(&couleur_statut[0], luminosite);
    Serial.println("Reset annulé");
    }
  if(StateBoutton == 1 && RESET == false && millisCheck-millisStart <appuilong-2000){ // affichage progressif de la LED
        displayColor(&couleur_error[0], 200*(millisCheck-millisStart)/(appuilong-2000));
        //Serial.println((String)(255*(millisCheck-millisStart)/(appuilong-2000)));
  }
  if(StateBoutton == 1 && RESET == false && millisCheck-millisStart >= appuilong-2000 && millisCheck-millisStart < appuilong){ //Led clignote avant validation du reset
          displayColor(&couleur_error[0], 100);   // turn the LED on (HIGH is the voltage level)
          delay(100);                       // wait for a 0,1 second
          displayColor(&COLOR_BLACK[0], 100);    // turn the LED off by making the voltage LOW
          delay(100);
  }
  if(StateBoutton == 1 && RESET == false && millisCheck-millisStart >=appuilong){ 
      StateBoutton=0;
      Serial.println("Appui de :"+(String)(millisCheck-millisStart)+"ms : Erase settings and restart ...");
      SPIFFS.remove("/config.json");
      wifiManager.resetSettings();  
      ESP.restart();  
  }
}

float inttofloat ( int value) {
  return (float)value/10;
}
 int floattoint (float value) {
  return(int)roundf(value*10);
}
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

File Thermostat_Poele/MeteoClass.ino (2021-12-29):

#include "meteo.h"

Meteo::Meteo(int nbenr, String nomfichier) /* : _Tab_Meteo(JSON_ARRAY_SIZE(nbenr) + nbenr*JSON_OBJECT_SIZE(4) + 20)*/{
  _SizeHistMeteo= nbenr; 
//  _nbenrmeteo = 0;
  _nomfichier = nomfichier;
}

void Meteo::Update(unsigned long datedemesure, float pressionmesure,float txHumidite, float qualiteAir){
 int i ;
 DynamicJsonDocument _Tab_Meteo (JSON_ARRAY_SIZE(_SizeHistMeteo) + _SizeHistMeteo*JSON_OBJECT_SIZE(4) + 20);
 File file = SPIFFS.open(_nomfichier, "r");
  if (!file){
    Serial.println("Aucun historique existe - " + _nomfichier);
    _Tab_Meteo[0]["d"] = datedemesure;
    _Tab_Meteo[0]["p"] = pressionmesure;
    _Tab_Meteo[0]["h"] = txHumidite;
    _Tab_Meteo[0]["iaq"] = qualiteAir;
  } else {
    if ( file.size() == 0 ) {
      Serial.println("Fichier historique vide !");
      _Tab_Meteo[0]["d"] = datedemesure;
      _Tab_Meteo[0]["p"] = pressionmesure;
      _Tab_Meteo[0]["h"] = txHumidite;
      _Tab_Meteo[0]["iaq"] = qualiteAir;
    } else {
      DeserializationError error = deserializeJson(_Tab_Meteo, file);
      if (error) {
        Serial.println("Impossible de lire le JSON");
        Serial.println(error.c_str());
        _Tab_Meteo[0]["d"] = datedemesure;
        _Tab_Meteo[0]["p"] = pressionmesure;
        _Tab_Meteo[0]["h"] = txHumidite;
        _Tab_Meteo[0]["iaq"] = qualiteAir;
      } else {
  //      Serial.println("Historique charge " + _nomfichier);
 //       serializeJson(_Tab_Meteo, Serial);
        Serial.println("date : " + (String)datedemesure + " Pression : " + (String)pressionmesure + " Tx humidite : " + (String)txHumidite + " IAQ : " + (String)qualiteAir);
        if (_Tab_Meteo.size()>= _SizeHistMeteo){
          //Serial.println("Suppression de la première valeur");
          for (i =1 ; i< _SizeHistMeteo ; i++){
            _Tab_Meteo[i-1]["d"] = _Tab_Meteo[i]["d"];
            _Tab_Meteo[i-1]["p"] = _Tab_Meteo[i]["p"];
            _Tab_Meteo[i-1]["h"] = _Tab_Meteo[i]["h"];
            _Tab_Meteo[i-1]["iaq"] = _Tab_Meteo[i]["iaq"];
          }
          //Serial.println("stockage en position : " + (String)(_SizeHistMeteo-1));
          _Tab_Meteo[(_SizeHistMeteo-1)]["d"] = datedemesure;
          _Tab_Meteo[(_SizeHistMeteo-1)]["p"] = pressionmesure;
          _Tab_Meteo[(_SizeHistMeteo-1)]["h"] = txHumidite;
          _Tab_Meteo[(_SizeHistMeteo-1)]["iaq"] = qualiteAir;
        } else {
          //Serial.println("stockage en position : " + (String)_nbenrmeteo);
          i = _Tab_Meteo.size();
          //Serial.println("size : " + (String)i);
          _Tab_Meteo[i]["d"] = datedemesure;
          _Tab_Meteo[i]["p"] = pressionmesure;
          _Tab_Meteo[i]["h"] = txHumidite;
          _Tab_Meteo[i]["iaq"] = qualiteAir;
        }
      }
    }
    
  }
 file.close();

// Serial.println("Enregistrement : " + (String)(nbenrmeteo+1) + " Timestamp : " + (String)datedemesure + " pression : " + (String)pressionmesure);
/* _nbenrmeteo++;
 if ( _nbenrmeteo > (_SizeHistMeteo -1) ) {
   Serial.println("maximum historique atteint");
   _nbenrmeteo = 0;
 }*/
// serializeJson(_Tab_Meteo,Serial);
 file  = SPIFFS.open(_nomfichier, "w");
 Serial.println("Sauvegarde des données " + _nomfichier);
// serializeJson(_Tab_Meteo, Serial);
 serializeJson(_Tab_Meteo, file);
 file.close();

}

Meteo::~Meteo(){
}

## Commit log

2020-12-10 Intégration schéma PCB
    [BOM_pilote_poele_2020-12-10_21-16-10.csv]
2020-12-10 correction absence PA Wifi et test perte de connexion
    [Thermostat_Poele.ino]
2020-12-14 Correction PCB inversion I2C
2020-12-14 Complément Serial Print des infos
2020-12-14 mondification des constantes pour PCB
2020-12-14 Correction rotation des fichiers + de 8j
    [Thermostat_Poele.ino]
2020-12-16 correction PCB I2C et port Relais D0 au lieu de D3
2020-12-16 Boitier 3D V0
    [Boitier_bas.FCStd, boitier_bas_V0.stl]
2020-12-16 Correction data corrompues dans un fichier
    [MeteoClass.ino]
2020-12-19 Correction données météo hebdo
    [Thermostat_Poele.ino]
2020-12-19 éEvolution boitier
    [Boitier_bas.FCStd, Boitier_couvercle.FCStd, couvercle_V0.stl]
2020-12-29 Prise en charge de l'écran LCD
2021-12-29 Update boitier
    [Boitier_couvercle.FCStd, Boitier_extension.FCStd]
2021-12-30 Update schematic PCB
